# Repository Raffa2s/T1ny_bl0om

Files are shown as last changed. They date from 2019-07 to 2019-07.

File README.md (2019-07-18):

# T1ny_bl0om (README IN PROGRESS)

This project was born as a my own exercise of soldering but it's grown in a more complex tiny project.

This project was inspired by this [video](https://www.youtube.com/watch?v=kN0PZbytzZM) from Adafruit and you can use this for your props, cosplay, or photoshooting give you the possibility to choose one (ore more) specific color and his own intensity and duration (in case you want a fade effect between different color).

## Getting Started

### Prerequisites

To achive this project you need basicaly 3 things:
* A soldering station
* A 3D printer capable of 0.1mm high, I had a FFF type but probably is better a SLA/SLS
* A Pc with arduino IDE on it and a ISP for flashing
On top of those  you need a lot of patiente but at the end of the story you will have a tiny little device that you can program fro your pc and is big as a 2€ coins.

### Photos

<p align="center">
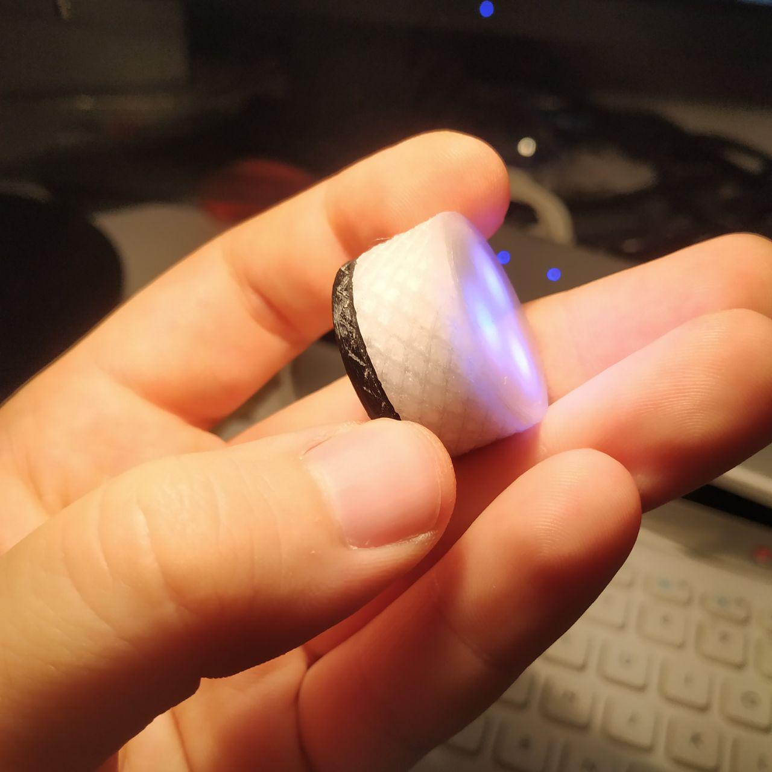
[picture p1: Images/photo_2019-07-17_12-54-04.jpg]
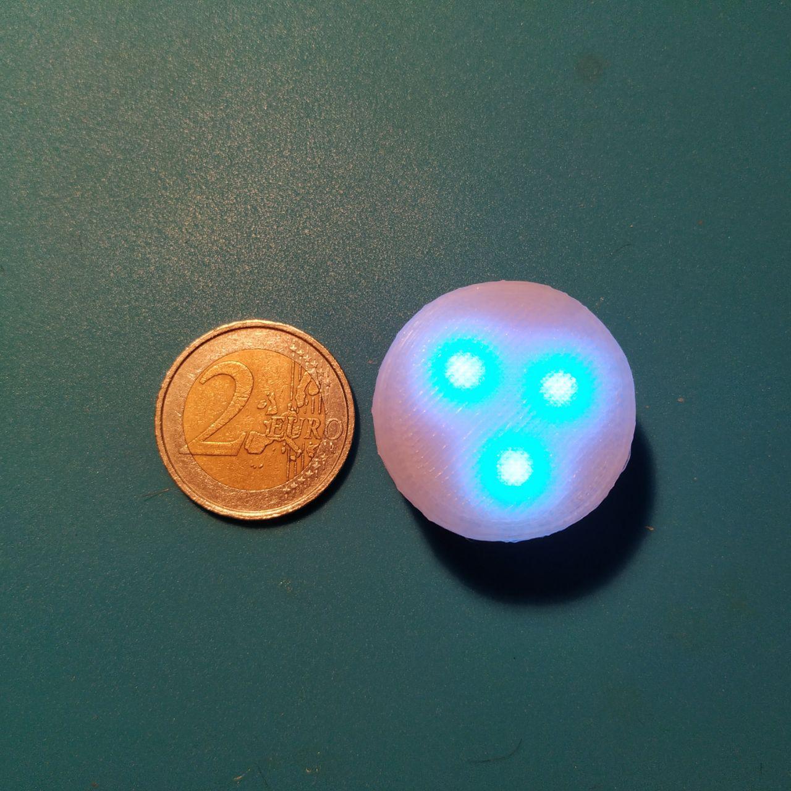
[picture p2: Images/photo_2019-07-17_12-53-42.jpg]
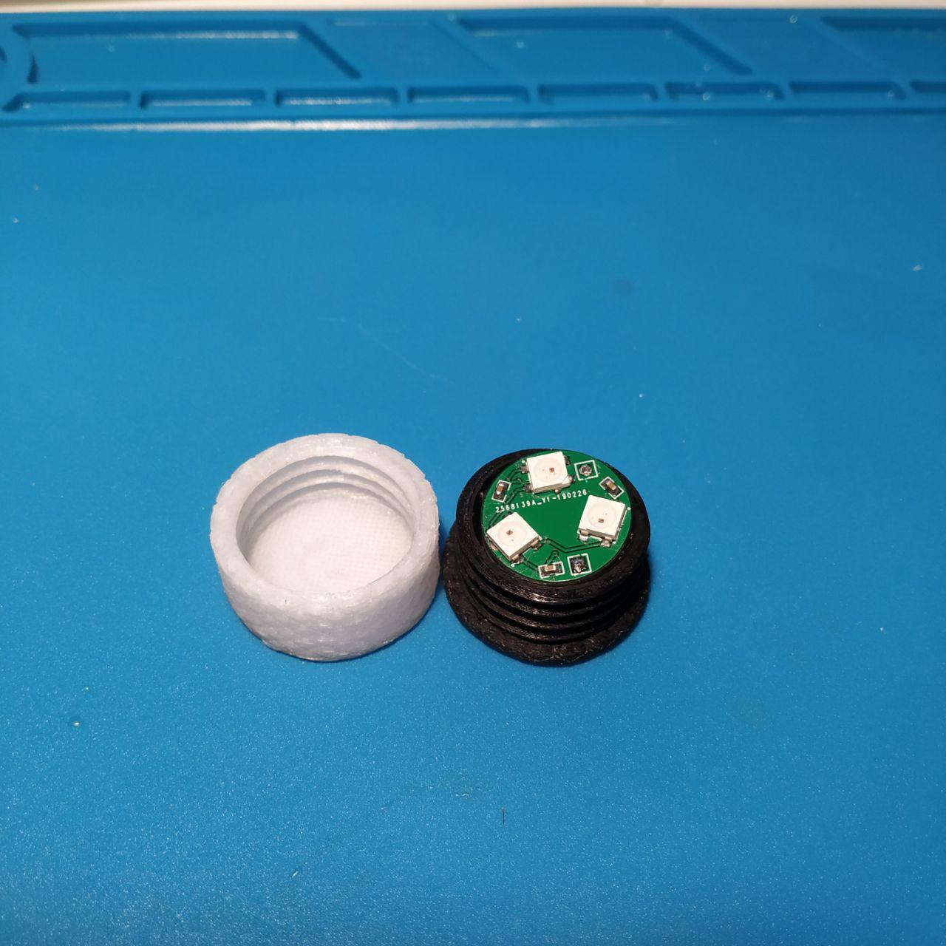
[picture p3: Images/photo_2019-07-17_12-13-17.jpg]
  
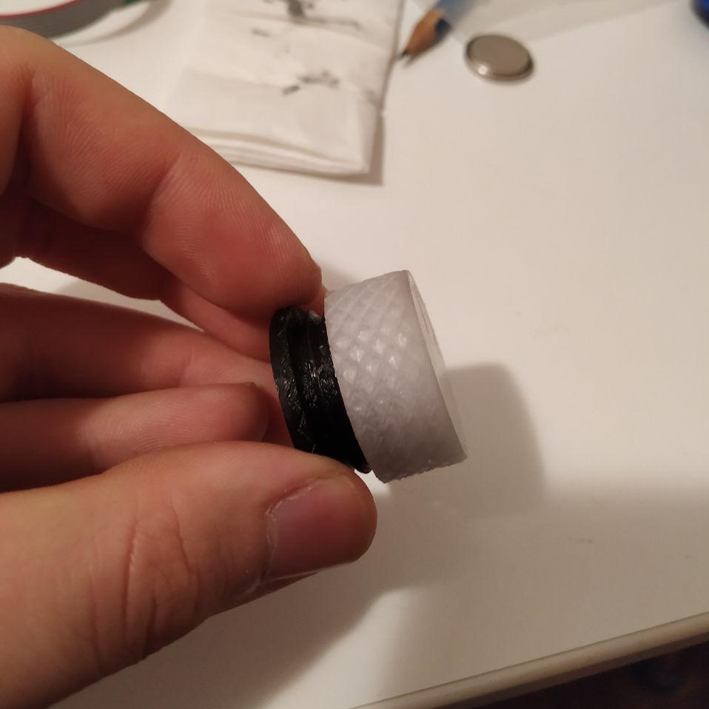
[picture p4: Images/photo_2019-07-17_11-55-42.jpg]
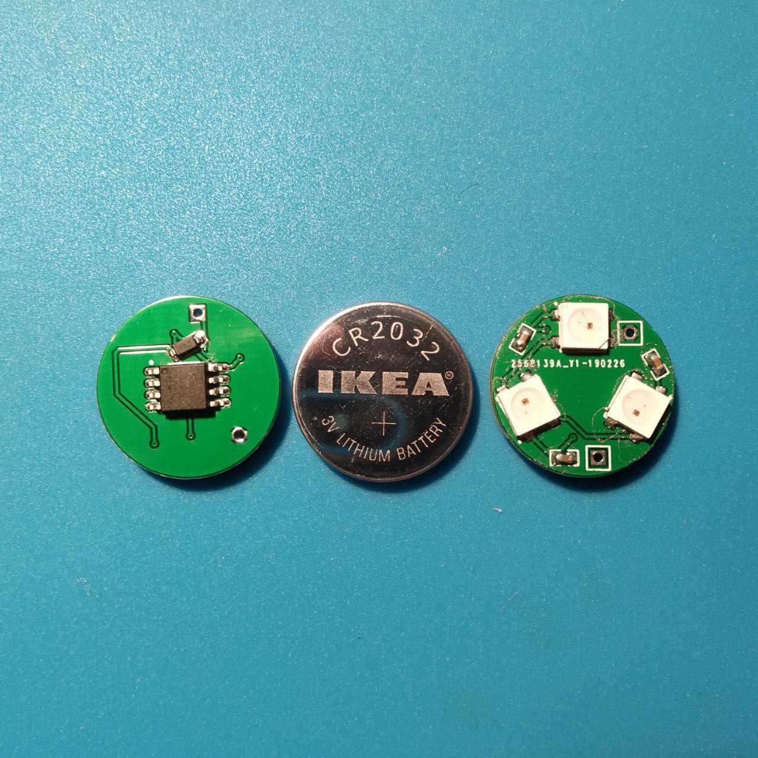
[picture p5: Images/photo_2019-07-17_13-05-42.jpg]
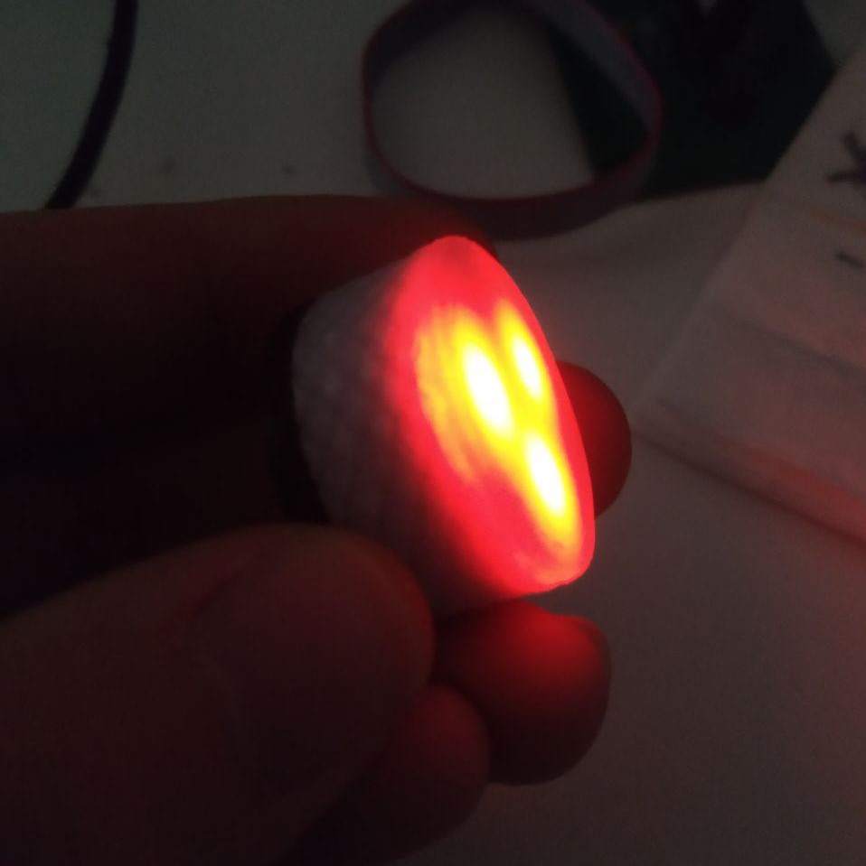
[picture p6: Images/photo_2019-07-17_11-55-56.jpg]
  
</p>

### General info
In each folder you can find, moreover the mandatory file, a README in which are included the BOM list of the phisical objects that you need and a little guide through the main steps to complete each part.

## Author

**Luca Raffaelli** - [Twitter](https://twitter.com/raffass)

If you remix this project or use it let me now :blush: I'm really curious :grin:

## License

This project is licensed under the MIT License - see the [LICENSE.md](LICENSE.md) file for details

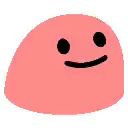
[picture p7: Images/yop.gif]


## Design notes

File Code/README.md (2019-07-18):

# T1ny_bl0om - Code

## Getting Started

### Requisites

Before start, is better to have completed the soldering part of the project because now it's time for flashing and programming :heart_eyes: :sparkles:

Remember to flash the arduino as ISP **BEFORE** solder it to the board, if you need an ISP to program the Attiny85.

### Steps
#### Set-up
First of all, if you have completed the soldering part, is important to:
- Had installed the Arduino IDE
- Install the adafruit library for the ws2812 in your Arduino IDE called *Adafruit_NeoPixel*
- Add the support for the Attiny85 in Arduino IDE, if you had problem follow the first 2 steps of this [guide](https://www.instructables.com/id/How-to-Program-an-Attiny85-From-an-Arduino-Uno/)

After the set-up of the Arduini IDE it's time to flash the Attiny85; to do so, is important to set the arduino to flash firstly the bootloader to the Attiny85 and after that we test it.

#### Burn the Bootloader

So it's important to set the arduino like the photo:
- Board: ATtiny25/45/45
- Processor: ATtiny85
- Clock: Internal 8 MHz
- Port: COMXX (matching your port)
- Programmer: Arduino as ISP

After that, it's time to flash the bootloader pressing the button *Burn the bootloader*.

<br />
<br />
<br />
<br />
<br />
<br />

<p align="center">
 
</p>

**Moreover is important do plug the clamp correctly!!!** if you brought the clam from the link in the elettronics README, is important to plug the female plug with the red wire up (like in the photo above) and clamp the attiny85 as the photo on the right ( the 2 attinys are place in the same way).

#### Test Code

If everything it's fine you can try to upload the code 'attiny_blink/attiny_blink.ino' that make the led in the flash board to blink periodically; after that you can upload the code 'Neopixel_Rainbow/Neopixel_Rainbow.ino'.

The code is fairly similar to the code example given by Adafruit with his own library.

In case you have any problems feel free to contact me on [Twitter](https://twitter.com/raffass).



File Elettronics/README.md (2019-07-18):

# T1ny_bl0om - Elettronics

## Getting Started

### Requisites
It's important to have the right hardware for the job, so this is mine:
- Soldering iron, mine is a Weller WHS 40
- Soldering station, mine is [this one](https://www.aliexpress.com/item/32817153181.html?spm=a2g0s.9042311.0.0.27424c4d8S5X5Y) Set E, that had a soldering iron and solder past
- Solder past, [mine](https://www.aliexpress.com/item/32623418957.html?spm=a2g0s.9042311.0.0.27424c4d8S5X5Y) but the one that came with the soldering station works fine
- Flux paste, [mine](https://www.aliexpress.com/item/32331668231.html?spm=a2g0s.9042311.0.0.27424c4dDTmYnn) and works fine
- Soldering fume extractor, [this](https://www.youtube.com/watch?v=gNbNKMQhCOQ) is very articuleted but it's important to have a kind of a extractor to evacuate the soldering fume

The following instractions is divide in two part:
- ISP
- T1ny_bl0om

If you have a flasher you can skip the ISP part and go straight to the T1ny_bl0om part.

### ISP

#### Build of Materials
In this part you need:
- An arduino nano [link](https://www.aliexpress.com/item/32341832857.html?spm=a2g0s.9042311.0.0.27424c4diAN1ap)
- A 10 μF capacitor, here you have a set of those [link](https://www.aliexpress.com/item/32866006892.html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)
- A 5mm led or similar [link](https://lcsc.com/product-detail/Light-Emitting-Diodes-LED_f5Short-legs-Round-with-edge-Super-bright-red-hair-red-Bagged-RHOS_C52721.html)
- A pcb, if you want you can upload directly the file *ISP/Flasher.zip* to [jlcpcb](https://jlcpcb.com/quote) or where do you want, I design the pcb with [EasyEDA](https://easyeda.com/) so if you want to modify it you can import the __*.json__ file inside EasyEDA
- A program clam [link](https://www.aliexpress.com/item/1902568501.html?spm=a2g0s.9042311.0.0.27424c4dFCbfAZ)
- Some pin [link](https://www.aliexpress.com/item/32933682566.html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)

#### Steps
It's basically soldiring at this point:
1. Solder the pin,led and capacitor to the board
2. Solder the pin to arduino nano
3. **Upload to the arduino the ISP sketch**
4. Solder arduino to the pcb

Complete :tada::tada::tada:

Now it's time for the tiny.

### T1ny_bl0om

#### Build of Materials
I order some part from LCSC and other form Aliexpress feel free to place the order where do you want, down below there is the list of all the mandatory component to complete **one** T1ny_bl0om:
- 1  pcb, if you want you can upload directly the file *T1ny_bl0om/T1ny_bl0om.zip* to [jlcpcb](https://jlcpcb.com/quote) or where do you want, I design the pcb with [EasyEDA](https://easyeda.com/) so if you want to modify it you can import the __*.json__ file inside EasyEDA
- 1 Attiny85 [link](https://lcsc.com/product-detail/FLASH_ATMEL_ATTINY85-20SU_ATTINY85-20SU_C89852.html)
- 3 WS2812B [link](https://www.aliexpress.com/item/32453497583.html?spm=a2g0s.9042311.0.0.27424c4d9DvwKP)
- 3 YAGEO CC0603KRX7R9BB104 [link](https://lcsc.com/product-detail/Multilayer-Ceramic-Capacitors-MLCC-SMD-SMT_100nF-104-10-50V_C14663.html)
- 1 Diodes MMSZ5233B-7-F [link](https://lcsc.com/product-detail/Zener-Diodes_DIODES_MMSZ5233B-7-F_MMSZ5233B-7-F_C151381.html)
- 2 pieces of wire to 'hug' the battery, one 20mm an the other 15mm
- Some copper stripes to enlarge the contact area, I used the one that came with the soldering station and works well

BTW I had uploaded the component list (*T1ny_bl0om\tiny_bloom_.csv*) in case you have problems.

#### Steps
So first I soldered first the top part (the one with led and capacitors) according to the scheme, and after that I soldered the bottom part (the one with attiny and zener diode).

The whole process is a bit bothersome due to the size of the SMD component but the final result :smile:

In case you have any problems feel free to contact me on [Twitter](https://twitter.com/raffass).



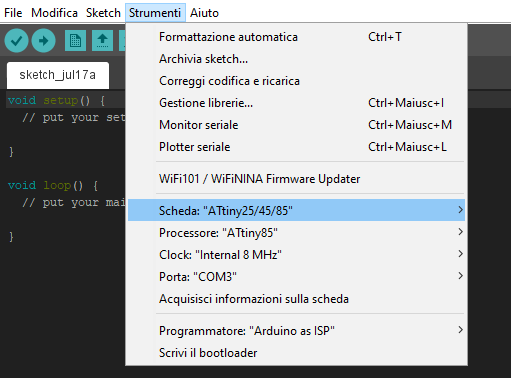
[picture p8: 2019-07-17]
Images/screen.PNG

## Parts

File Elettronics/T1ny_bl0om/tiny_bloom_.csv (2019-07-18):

ID | Name | Designator | Footprint | Quantity | Manufacturer Part | Manufacturer | Supplier | Supplier Part
1 | ATTINY85-20SU | U1 | SOIC-8_208MIL | 1 | ATTINY85-20SU | MICROCHIP | LCSC | C89852
2 | WS2812B | LED1,LED2,LED3 | LED-5050_4P | 3 | WS2812B | Worldsemi | LCSC | C114585
3 | 1u | C1,C2,C3 | 0603' | 3 | ?
4 | Header-Male-2.54_1x1 | GND,VCC | HDR-1X1/2.54 | 2 | Header-Male-2.54_1x1 | ReliaPro | LCSC | C81276
5 | MMSZ5233B-7-F | D1 | SOD-123FL | 1 | MMSZ5233B-7-F | DIODES | LCSC | C151381

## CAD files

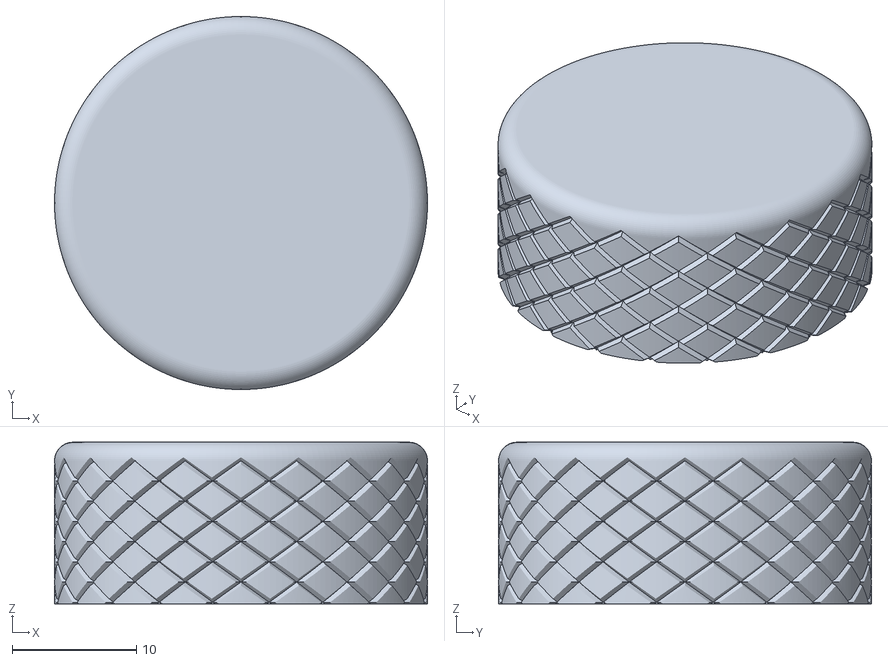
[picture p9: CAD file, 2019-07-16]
3D printing/Top.stl
30.0 x 30.0 x 13.0

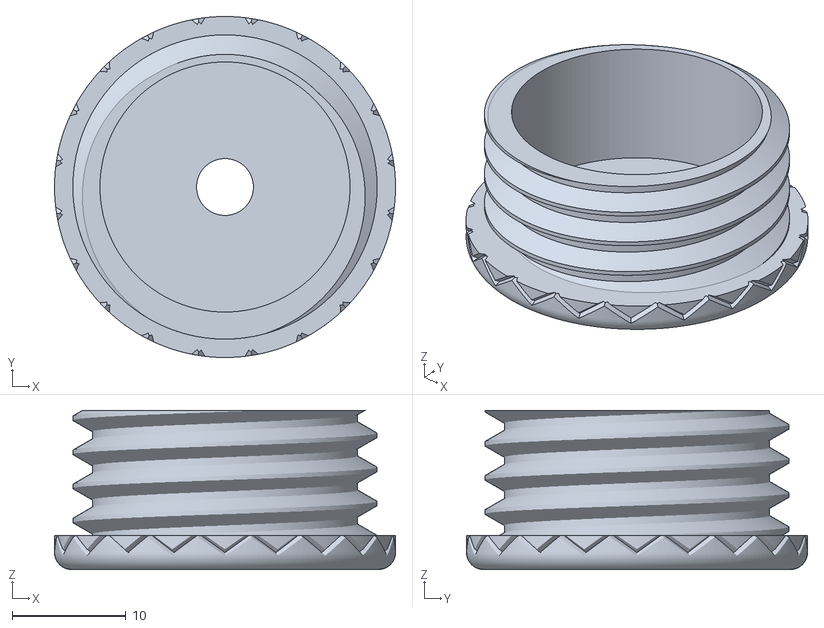
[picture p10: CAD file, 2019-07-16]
3D printing/Bottom.stl
30.0 x 30.0 x 14.0

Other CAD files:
3D printing/T1ny_bl0om.f3d

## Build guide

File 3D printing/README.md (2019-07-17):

# T1ny_bl0om - 3D Printing

## Getting Started

### Requisites

Before start, is better to have all this things ready:
- A 3D printer capable of 0.1mm high, I had a FFF type but probably is better a SLA/SLS
- A Clear filament (in my case it was a petg from Creozone [Link](https://www.aliexpress.com/item/32830591502.html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)
- An opaque or black filament (in my case it was a petg from Prusa [Link](https://shop.prusa3d.com/en/prusament/802-prusament-petg-jet-black-1kg.html)

For the settings, everything is good if allow you to achive a good finished print with the minimum efford; by the way is important to have setted:
- Layer high: 0.1mm
- Infill: 100%

Over that is really important to have:
- A good compensation for the SKEW (if you have a problem or don't know how to do, please see this [video](https://www.youtube.com/watch?v=YfAb5IaHDSo))
- A good flow settings (if you don't know how to do, try this test from [Thingiverse](https://www.thingiverse.com/thing:342198))

### Steps
It's pretty straight forward:
- Download
- Slice with the setting above (remember to rotate the Top.stl)
- Print
- Test fit

In case you have any problems feel free to contact me on [Twitter](https://twitter.com/raffass).



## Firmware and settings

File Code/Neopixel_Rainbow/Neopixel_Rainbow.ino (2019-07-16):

#include <Adafruit_NeoPixel.h>

// constants won't change. They're used here to 
// set pin numbers:
const int ledPin = 4;     // the number of the neopixel strip
const int numLeds = 3;

//Adafruit_NeoPixel pixels = Adafruit_NeoPixel(8, ledPin);
Adafruit_NeoPixel strip = Adafruit_NeoPixel(numLeds, ledPin, NEO_GRB + NEO_KHZ800);


void setup() {
  strip.begin();
  strip.setBrightness(122); // 1/3 brightness

}

void loop() {

    
    rainbow(30);
    
  delay(10);


}


void rainbow(uint8_t wait) {
  uint16_t i, j;

  for(j=0; j<256; j++) {
    for(i=0; i<strip.numPixels(); i++) {
      strip.setPixelColor(i, Wheel((i*1+j) & 255));
    }
    strip.show();
    delay(wait);
  }
}


// Input a value 0 to 255 to get a color value.
// The colours are a transition r - g - b - back to r.
uint32_t Wheel(byte WheelPos) {
  if(WheelPos < 85) {
    return strip.Color(WheelPos * 3, 255 - WheelPos * 3, 0);
  } 
  else if(WheelPos < 170) {
    WheelPos -= 85;
    return strip.Color(255 - WheelPos * 3, 0, WheelPos * 3);
  } 
  else {
    WheelPos -= 170;
    return strip.Color(0, WheelPos * 3, 255 - WheelPos * 3);
  }
}

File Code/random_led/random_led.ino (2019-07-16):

#include <Adafruit_NeoPixel.h>
long randNumber;
#define PIN            4

#define NUMPIXELS      3
Adafruit_NeoPixel pixels = Adafruit_NeoPixel(NUMPIXELS, PIN, NEO_GRB + NEO_KHZ800);
int delayval = 100;

void setup() {

  pixels.begin();

  randomSeed(analogRead(0));

}

void loop() {

  int r = random(128);

  int g = random(128);

  int b = random(128);
     
      
      for(int i=0;i<NUMPIXELS;i++){

      pixels.setPixelColor(i, pixels.Color(r,g,b));

      pixels.show(); // This sends the updated pixel color to the hardware.

      delay(delayval); // Delay for a period of time (in milliseconds).

       }
}
